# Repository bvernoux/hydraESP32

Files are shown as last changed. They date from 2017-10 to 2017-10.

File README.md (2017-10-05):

# hydraESP32

HydraESP32 HydraBus v1.0 Shield for ESP-WROOM-32 V1.1 Rev1.0 (Tested) 

https://oshpark.com/shared_projects/dgKJqznH

HydraBus Shield / Breakout board for ESP-WROOM-32 or ESP-32S.

This shield can be used with or without HydraBus board, you can even cut HydraBus specific right side (on the line) to have a tiny ESP-WROOM-32 breakout board.

It is not mandatory to solder the components on this shield in order to use it, you will just need to connect +3v3 on VCC Pin header 

* New features versus previous version [V1.0 Rev1.1](https://oshpark.com/shared_projects/6t5hURXL):
   * Added LDO (TPS73633DBVR SOT23-5) to convert 5V(VUSB) to a clean VCC (+3.3v) for ESP32 and which can be enabled by an HydraBus Pin or  with a JUMPER on J7 (which connect +3.3V from HydraBus to EN of the LDO)
   * Added VCC connector in order to measure ESP32 current/power consumption (if not used to measure current just add a JUMPER on VCC to power the ESP32)
   * Added J6 connector to have access to ESP32 SPI FLASH IOs (now all pins are available)

* This shield can be used only on bottom of HydraBus board (in order to use other shields on top of HydraBus)

* The [HydraBus board](http://hydrabus.com/hydrabus-1-0-specifications/) is a small (60mm x 37mm) and [low cost](http://hydrabus.com/buy-online/), multi-tool extensible board with STM32F405 Cortex M4F 32bits MCU @168MHz with a fully open source firmware [hydrafw](https://github.com/bvernoux/hydrafw) and full online documentation [hydrafw wiki](https://github.com/bvernoux/hydrafw/wiki)

* The ESP-WROOM-32 is a low-power 32-bit 240 MHz dual core MCU Wi-
Fi+BLE combo module that highly integrates TCP/IP network stacks, 12-
bit ADC and HSPI/SDIO/UART/PWM/I2C/I2S interfaces.
See [ESP32 Overview](http://www.espressif.com/en/products/hardware/esp32/overview), [ESP-WROOM-32 link/info](https://espressif.com/en/producttype/esp-wroom-32), [Espressif Products Overview including ESP-WROOM-32 PDF](http://www.elinistech.com/images/esp8266/Espressif%20Introduction-EN.pdf)

* Design based on official [esp_wroom_32_datasheet_en.pdf (September 26, 2016)](https://espressif.com/sites/default/files/documentation/esp_wroom_32_datasheet_en.pdf)

BOM:

| Qty | Value | Device | Package | Parts | Description |
|---|---|---|---|---|---|
| 1 | - | ESP_WROOM_32 or ESP-32S | ESP-WROOM-32 or ESP-32S | U1 | Espressif ESP-WROOM-32 or ESP-32S Module |
| 1 | - | TPS73633 | SOT23-5L | U2 | Texas Instrument LDO |
| 1 | 2.2uF | CAPACITOR_NPOL-0603 | C603 | C1 | SMD Non-Polarized capacitor |
| 1 | 1uF | CAPACITOR_NPOL-0603 | C603 | C2 | SMD Non-Polarized capacitor |
| 2 | 100nF | CAPACITOR_NPOL-0603 | C603 | C3, C4 | SMD Non-Polarized capacitor |
| 2 | 10K | RESISTOR-0603 | R603 | R1, R2 | SMD Resistor |
| 1 | - | | HYDRABUS_SHIELD_M2X7  | J1 | 2x7 Pin header |
| 4 | - | | HYDRABUS_SHIELD_M2X10 |J2, J3, J4, J5 | 2x10 Pin header |
| 2 | - | | HYDRABUS_SHIELD_M1X6  | J6, SWD_DEBUG | 1x6 Pin header |
| 2 | - | | Jumper - 2 Pin  | J7, VCC |  Jumper 2 Pin |
| 2 | - | | CON_HEADER_1X02-PTH | J7, VCC | 1x2 Pin header |

Note1: LDO U2 can be also replaced by MIC5319-3.3YD5-TR (Microchip)

Note2: If you do not want to solder those components you can avoid them and directly connect HydraBus 3v3 to VCC Pin near J5 marking

For more details see also [HydraBus_1_0_Shield_ESP_WROOM_32_v1_1_Rev1_BOM.csv](HydraBus_1_0_Shield_ESP_WROOM_32_v1_1_Rev1_BOM.csv)

Tested with success with an ESP-32S Module from Ai-Thinker (it is recommended to use official Espressif ESP-WROOM-32)

HydraBus__Shield_ESP_WROOM_32_v1_1_Rev1 with ESP-32S

HydraBus_1_0_Shield_ESP_WROOM_32_v1_1_Rev1_Top:
[HydraBus_1_0_Shield_ESP_WROOM_32_v1_1_Rev1_Top](HydraBus_1_0_Shield_ESP_WROOM_32_v1_1_Rev1_Top.png)

HydraBus_1_0_Shield_ESP_WROOM_32_v1_1_Rev1_Bottom:
[HydraBus_1_0_Shield_ESP_WROOM_32_v1_1_Rev1_Bottom](HydraBus_1_0_Shield_ESP_WROOM_32_v1_1_Rev1_Bottom.png)

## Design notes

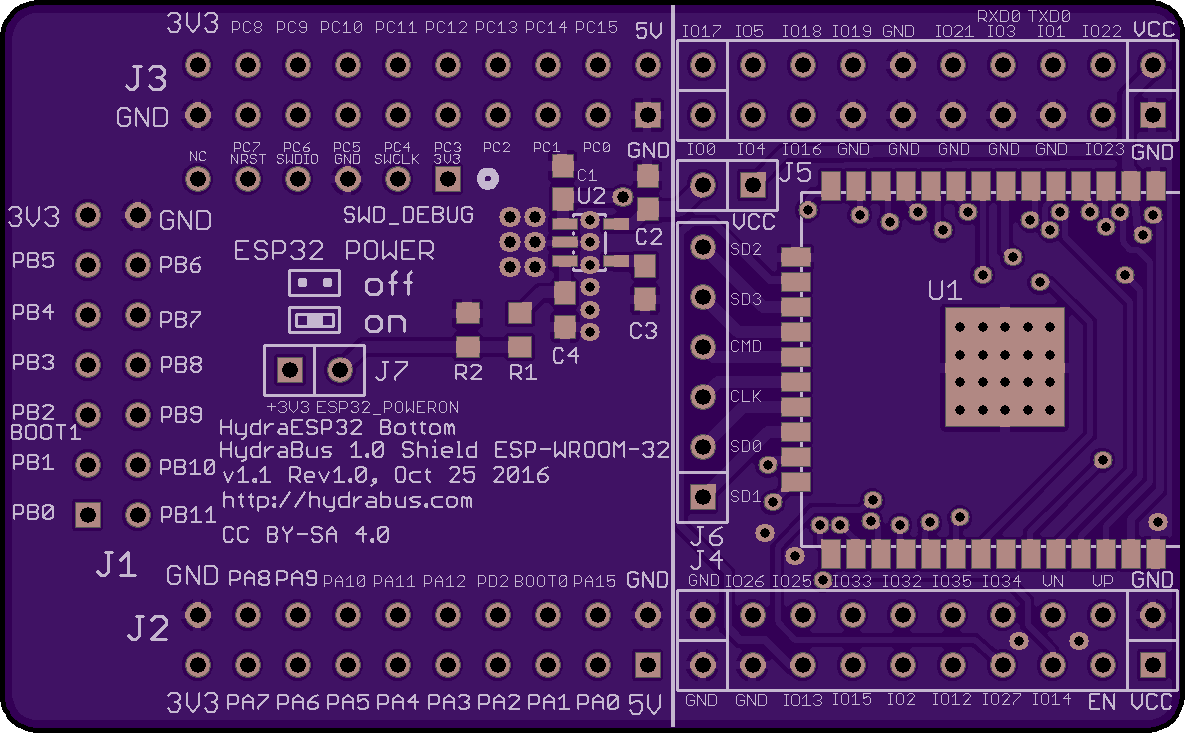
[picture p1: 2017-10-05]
HydraBus_1_0_Shield_ESP_WROOM_32_v1_1_Rev1_Bottom.png

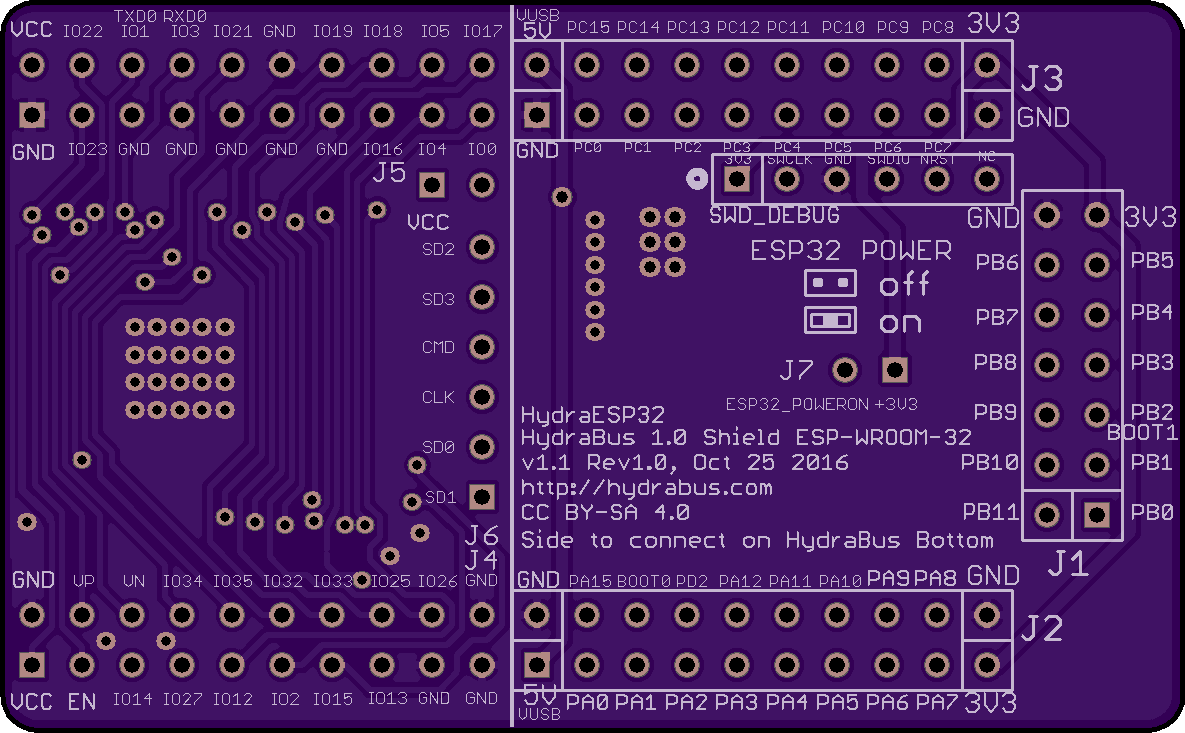
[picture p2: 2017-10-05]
HydraBus_1_0_Shield_ESP_WROOM_32_v1_1_Rev1_Top.png

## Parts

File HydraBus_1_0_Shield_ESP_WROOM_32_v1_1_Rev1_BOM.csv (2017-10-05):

Qty | Value | Device | Package | Parts | Description
1 | - | ESP_WROOM_32 | ESP_WROOM_32 | U1 | ESP_WROOM_32 Module 09 Aug 2016
2 | 100nF | CAPACITOR_NPOL-0603 | C603 | C3, C4 | Non-Polarized capacitor in various packages
2 | 10K | RESISTOR-0603 | R603 | R1, R2
1 | 1uF | CAPACITOR_NPOL-0603 | C603 | C2 | Non-Polarized capacitor in various packages
1 | 2.2uF | CAPACITOR_NPOL-0603 | C603 | C1 | Non-Polarized capacitor in various packages
2 | CON_HEADER_1X02-PTH | CON_HEADER_1X02-PTH | M1X2 | J7, VCC
1 | HYDRABUS_SHIELD_CON_HEADER_1X06 | HYDRABUS_SHIELD_CON_HEADER_1X06 | HYDRABUS_SHIELD_M1X6 | J6 | SWD Header 1x6 Pin header
1 | HYDRABUS_SHIELD_CON_HEADER_1X06_BOTTOM | HYDRABUS_SHIELD_CON_HEADER_1X06_BOTTOM | HYDRABUS_SHIELD_M1X6_BOTTOM | SWD_DEBUG | SWD Header 1x6 Pin header bottom
1 | HYDRABUS_SHIELD_CON_HEADER_2X07_BOTTOM | HYDRABUS_SHIELD_CON_HEADER_2X07_BOTTOM | HYDRABUS_SHIELD_M2X7_BOTTOM | J1 | 2x7 Pin header bottom
2 | HYDRABUS_SHIELD_CON_HEADER_2X10 | HYDRABUS_SHIELD_CON_HEADER_2X10 | HYDRABUS_SHIELD_M2X10 | J4, J5 | 2x10 Pin header
2 | HYDRABUS_SHIELD_CON_HEADER_2X10_BOTTOM | HYDRABUS_SHIELD_CON_HEADER_2X10_BOTTOM | HYDRABUS_SHIELD_M2X10_BOTTOM | J2, J3 | 2x10 Pin header bottom
1 | TPS73633 | TPS73633 | SOT23-5L | U2 | Texas Instrument LDO

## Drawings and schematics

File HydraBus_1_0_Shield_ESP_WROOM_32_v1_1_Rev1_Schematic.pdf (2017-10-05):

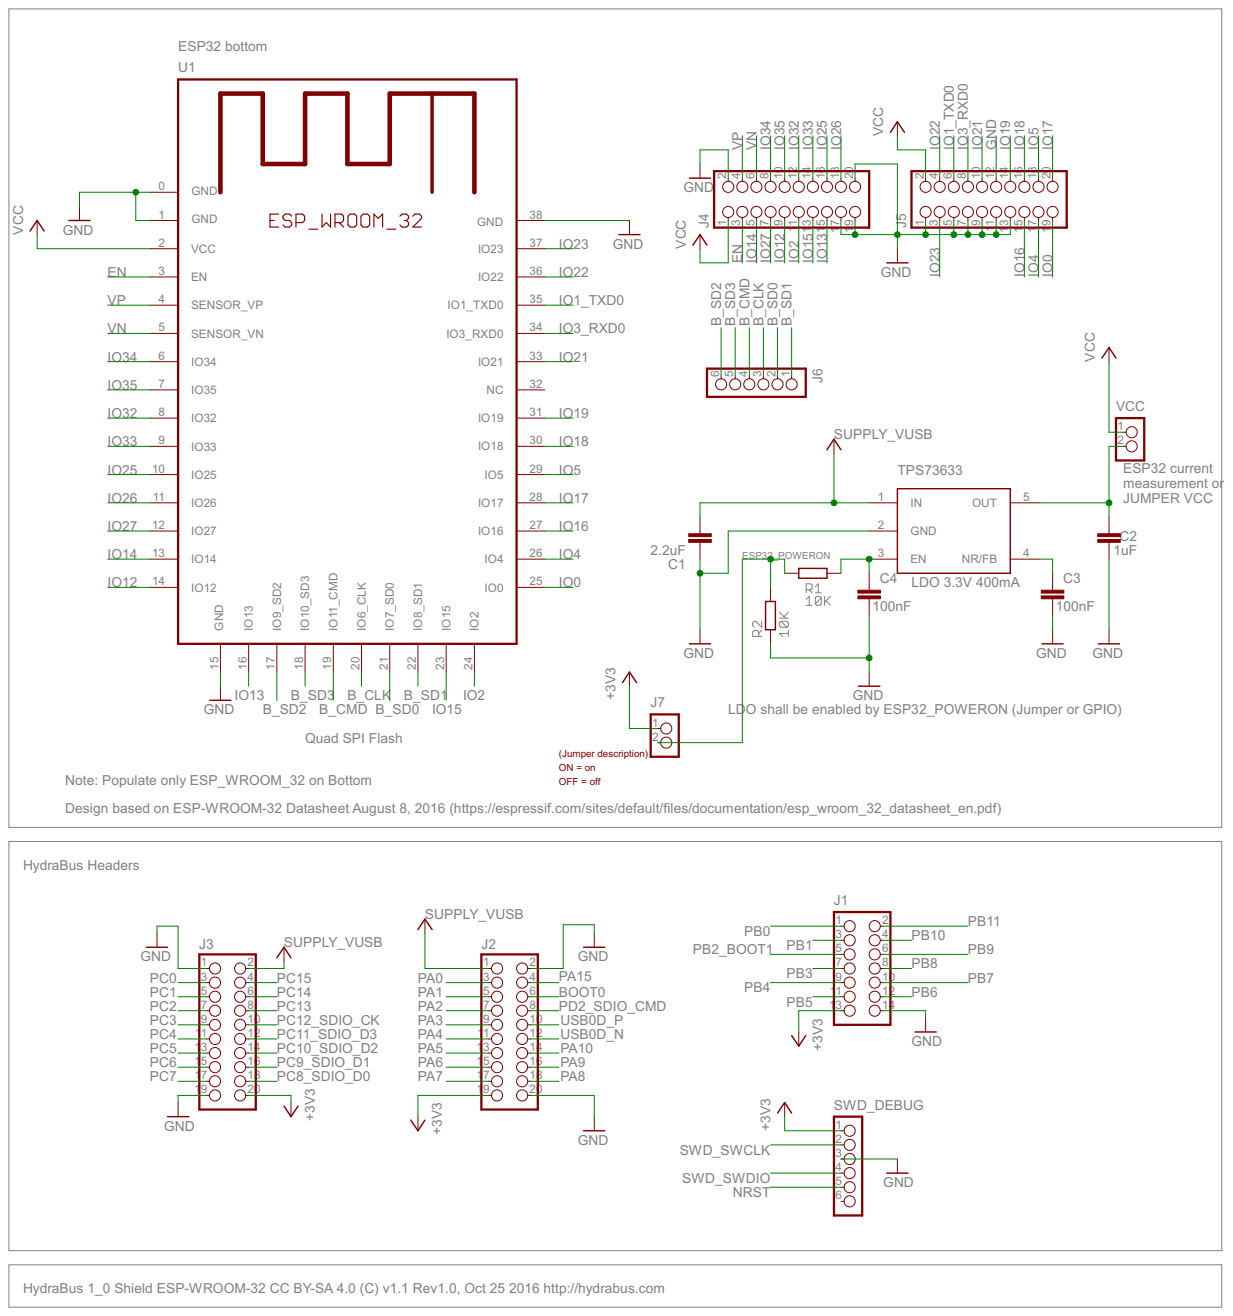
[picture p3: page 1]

ESP32 current measurement or JUMPER VCC
1uF GND

LDO shall be enabled by ESP32_POWERON (Jumper or GPIO)

Quad SPI Flash Design based on ESP-WROOM-32 Datasheet August 8, 2016 (https://espressif.com/sites/default/files/documentation/esp_wroom_32_datasheet_en.pdf)

(Jumper description) ON = on OFF = off

Note: Populate only ESP_WROOM_32 on Bottom

HydraBus 1_0 Shield ESP-WROOM-32 CC BY-SA 4.0 (C) v1.1 Rev1.0, Oct 25 2016 http://hydrabus.com

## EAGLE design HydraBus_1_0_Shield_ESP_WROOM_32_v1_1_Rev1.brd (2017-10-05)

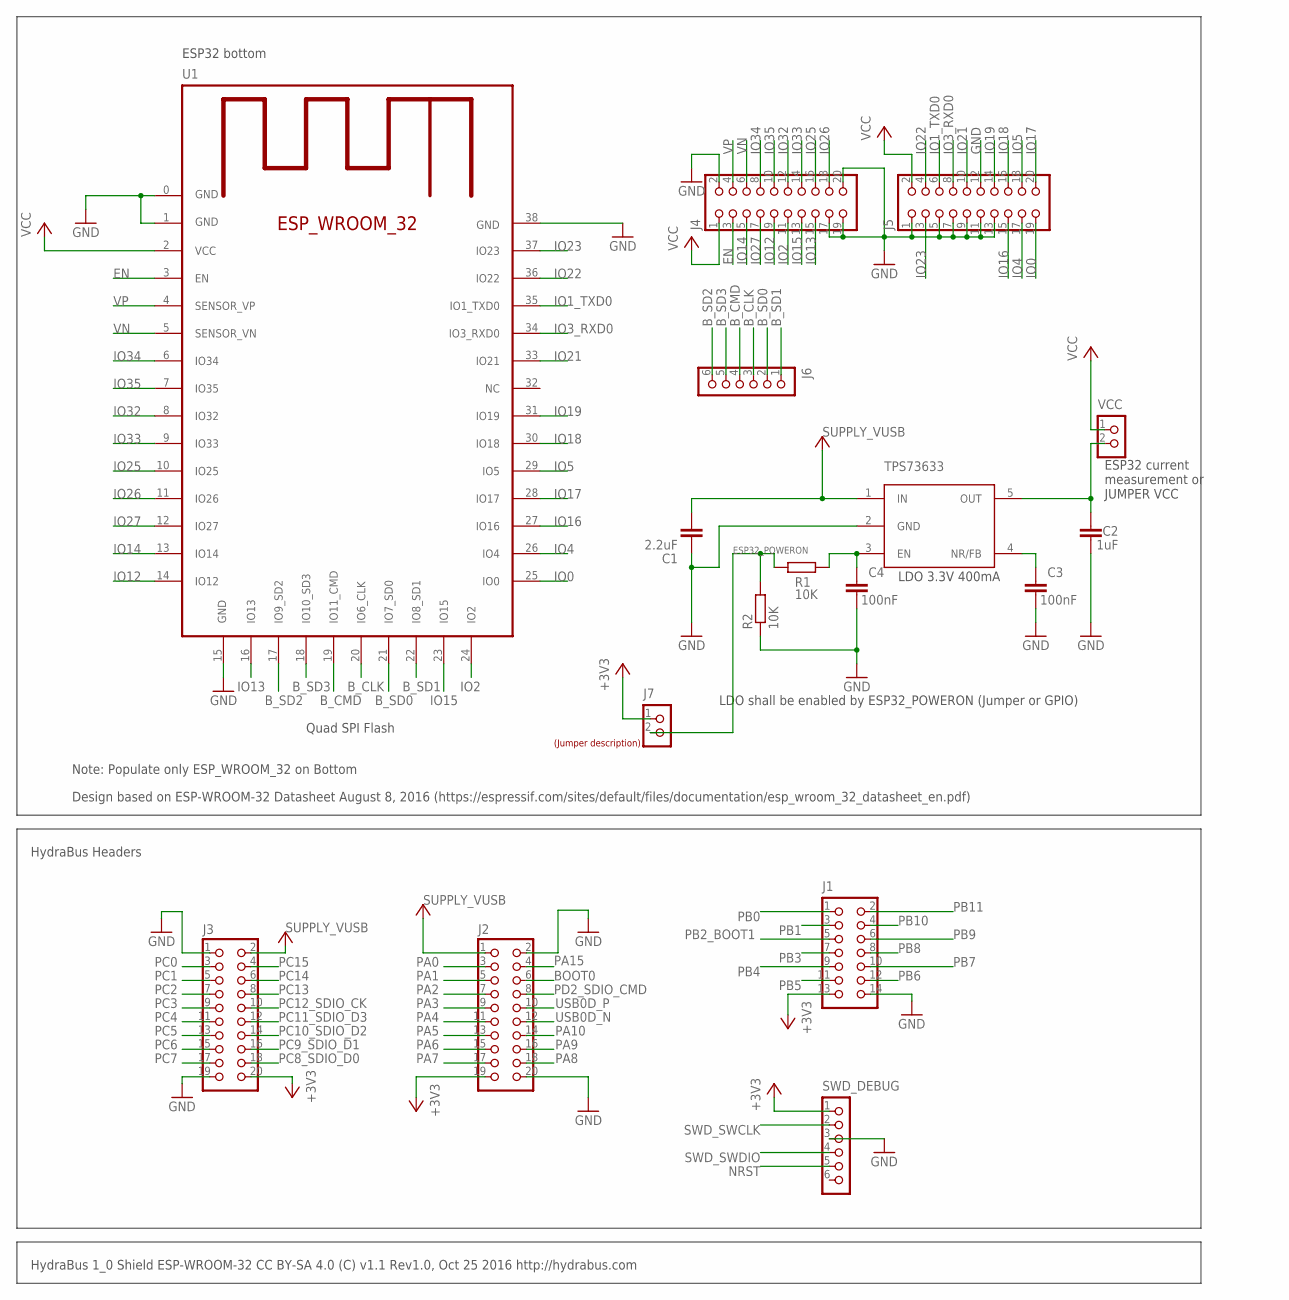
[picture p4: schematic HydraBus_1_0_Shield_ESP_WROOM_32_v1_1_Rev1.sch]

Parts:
C1: 2.2uF; C603
C2: 1uF; C603
C3, C4: 100nF; C603
J1: HYDRABUS_SHIELD_CON_HEADER_2X07_BOTTOM; HYDRABUS_SHIELD_M2X7_BOTTOM
J2, J3: HYDRABUS_SHIELD_CON_HEADER_2X10_BOTTOM; HYDRABUS_SHIELD_M2X10_BOTTOM
J4, J5: HYDRABUS_SHIELD_CON_HEADER_2X10; HYDRABUS_SHIELD_M2X10
J6: HYDRABUS_SHIELD_CON_HEADER_1X06; HYDRABUS_SHIELD_M1X6
J7: CON_HEADER_1X02-PTH; M1X2
R1, R2: 10K; R603
SWD_DEBUG: HYDRABUS_SHIELD_CON_HEADER_1X06_BOTTOM; HYDRABUS_SHIELD_M1X6_BOTTOM
U1: ESP_WROOM_32
U2: TPS73633; SOT23-5L
U$1: LABEL_JUMPER_1X2; JUMP2_DESC
VCC: CON_HEADER_1X02-PTH; M1X2

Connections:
+3V3: J1.13, J2.19, J3.20, J7.1, SWD_DEBUG.1
BOOT0: J2.6
B_CLK: J6.3, U1.20 (IO6_CLK)
B_CMD: J6.4, U1.19 (IO11_CMD)
B_SD0: J6.2, U1.21 (IO7_SD0)
B_SD1: J6.1, U1.22 (IO8_SD1)
B_SD2: J6.6, U1.17 (IO9_SD2)
B_SD3: J6.5, U1.18 (IO10_SD3)
EN: J4.3, U1.3 (EN)
ESP32_POWERON: J7.2, R1.1, R2.2
GND: C1.1, C2.1, C3.1, C4.1, J1.14, J2.2, J2.20, J3.1, J3.19, J4.2, J4.17, J4.19, J4.20, J5.1, J5.5, J5.7, J5.9, J5.11, J5.12, J5.13, R2.1, SWD_DEBUG.3, U1.0 (GND), U1.1 (GND), U1.15 (GND), U1.38 (GND), U2.2 (GND)
IO0: J5.19, U1.25 (IO0)
IO1_TXD0: J5.6, U1.35 (IO1_TXD0)
IO2: J4.11, U1.24 (IO2)
IO3_RXD0: J5.8, U1.34 (IO3_RXD0)
IO4: J5.17, U1.26 (IO4)
IO5: J5.18, U1.29 (IO5)
IO12: J4.9, U1.14 (IO12)
IO13: J4.15, U1.16 (IO13)
IO14: J4.5, U1.13 (IO14)
IO15: J4.13, U1.23 (IO15)
IO16: J5.15, U1.27 (IO16)
IO17: J5.20, U1.28 (IO17)
IO18: J5.16, U1.30 (IO18)
IO19: J5.14, U1.31 (IO19)
IO21: J5.10, U1.33 (IO21)
IO22: J5.4, U1.36 (IO22)
IO23: J5.3, U1.37 (IO23)
IO25: J4.16, U1.10 (IO25)
IO26: J4.18, U1.11 (IO26)
IO27: J4.7, U1.12 (IO27)
IO32: J4.12, U1.8 (IO32)
IO33: J4.14, U1.9 (IO33)
IO34: J4.8, U1.6 (IO34)
IO35: J4.10, U1.7 (IO35)
unnamed: C3.2, U2.4 (NR/FB)
unnamed: C4.2, R1.2, U2.3 (EN)
unnamed: C2.2, U2.5 (OUT), VCC.2
NRST: SWD_DEBUG.5
PA0: J2.3
PA1: J2.5
PA2: J2.7
PA3: J2.9
PA4: J2.11
PA5: J2.13
PA6: J2.15
PA7: J2.17
PA8: J2.18
PA9: J2.16
PA10: J2.14
PA15: J2.4
PB0: J1.1
PB1: J1.3
PB2_BOOT1: J1.5
PB3: J1.7
PB4: J1.9
PB5: J1.11
PB6: J1.12
PB7: J1.10
PB8: J1.8
PB9: J1.6
PB10: J1.4
PB11: J1.2
PC0: J3.3
PC1: J3.5
PC2: J3.7
PC3: J3.9
PC4: J3.11
PC5: J3.13
PC6: J3.15
PC7: J3.17
PC8_SDIO_D0: J3.18
PC9_SDIO_D1: J3.16
PC10_SDIO_D2: J3.14
PC11_SDIO_D3: J3.12
PC12_SDIO_CK: J3.10
PC13: J3.8
PC14: J3.6
PC15: J3.4
PD2_SDIO_CMD: J2.8
SWD_SWCLK: SWD_DEBUG.2
SWD_SWDIO: SWD_DEBUG.4
USB0D_N: J2.12
USB0D_P: J2.10
VCC: J4.1, J5.2, U1.2 (VCC), VCC.1
VN: J4.6, U1.5 (SENSOR_VN)
VP: J4.4, U1.4 (SENSOR_VP)
VUSB: C1.2, J2.1, J3.2, U2.1 (IN)

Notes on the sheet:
HydraBus 1_0 Shield ESP-WROOM-32 CC BY-SA 4.0 (C) v1.1 Rev1.0, Oct 25 2016 http://hydrabus.com
HydraBus Headers
ESP32 bottom
Note: Populate only ESP_WROOM_32 on Bottom
Quad SPI Flash
Design based on ESP-WROOM-32 Datasheet August 8, 2016 (https://espressif.com/sites/default/files/documentation/esp_wroom_32_datasheet_en.pdf)
LDO 3.3V 400mA
LDO shall be enabled by ESP32_POWERON (Jumper or GPIO)
ESP32 current measurement or JUMPER VCC

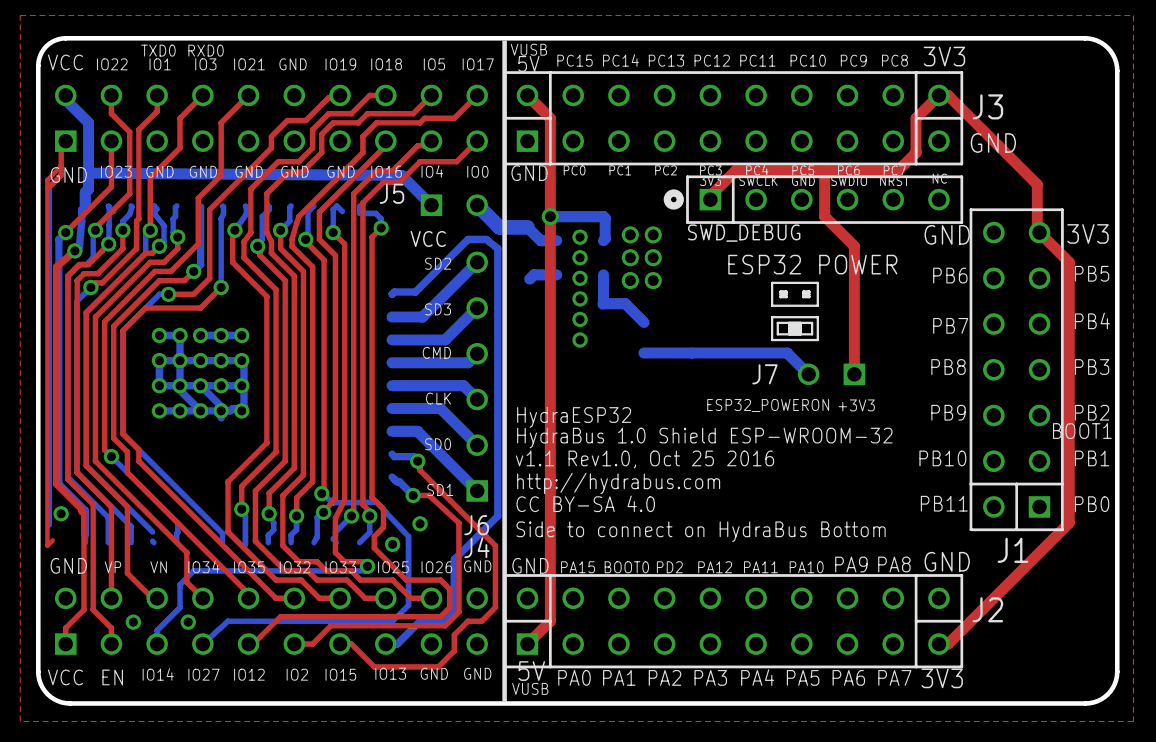
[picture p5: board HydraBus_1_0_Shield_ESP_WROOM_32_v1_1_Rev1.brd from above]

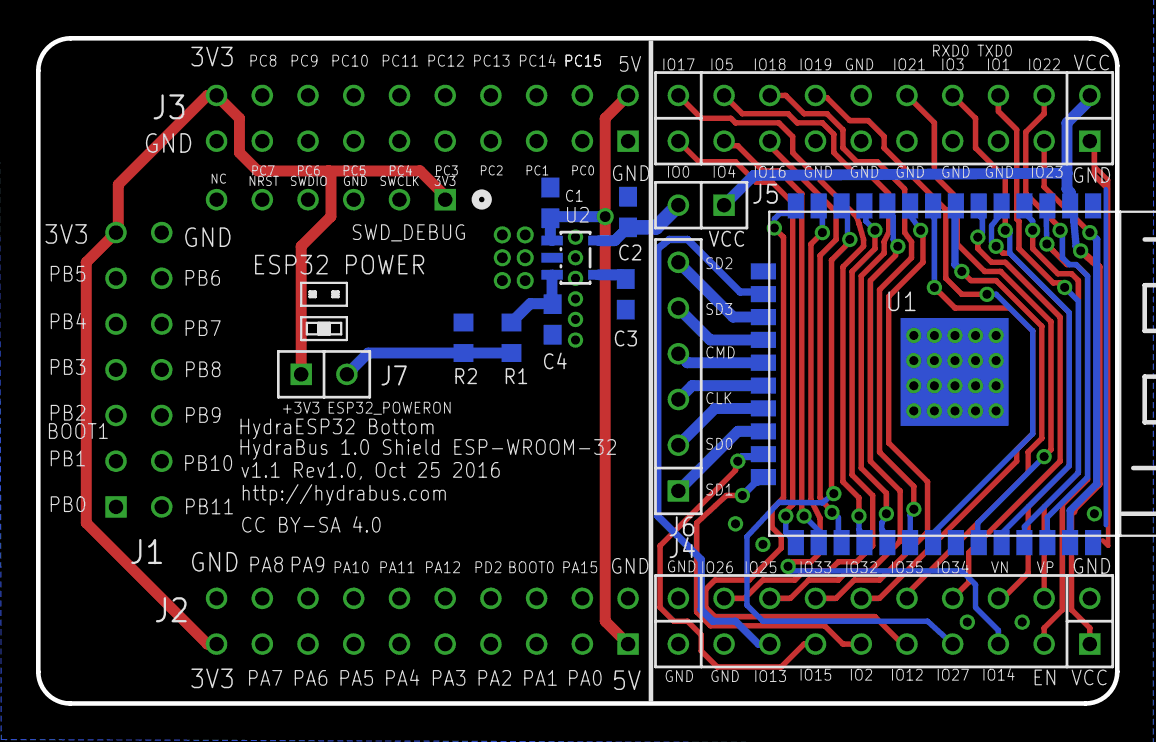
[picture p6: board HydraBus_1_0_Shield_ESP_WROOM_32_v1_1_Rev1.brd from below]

Board: 2 copper layers, 59.9 x 37.0 mm, 19 parts (11 on the bottom side), 41 nets.

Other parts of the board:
U$2: LABEL_JUMPER_1X2; JUMP2_DESC
